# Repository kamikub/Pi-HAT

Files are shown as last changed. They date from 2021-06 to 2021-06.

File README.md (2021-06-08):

# PiHat_Group18

This is Group 18's Git repo, containing all relevant documentation, schematic, PCB and simulation files for the design of our PiHat.

The PiHat we designed is a frequency tuner: the user will be able to select a desired sound-frequency or pitch to listen for via a series of push buttons and through the operation of an onboard microphone, instrumentation op-amp and code written to the Pi, the PiHat will indicate whether the desired frequency is acquired or not (using LED's and a buzzer).

This repo includes all schematics, PCB, simulations and other relevant documentation that went into the design of this PiHat. For the most part, this was a modular design process – our PiHat was broken down into three submodules: power supply, LED/buzzer interface and operational amplifier. These submodules were individually designed and simulated on LTSpice and KiCad. The integration of all three submodules was developed on KiCad by means of a final PCB design of the PiHat as a whole.

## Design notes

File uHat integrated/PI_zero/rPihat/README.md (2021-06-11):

# Raspberry Pi Zero ~~pHat~~ uHat template

This a KiCad 5.0.0 template for a [Raspberry Pi Zero](https://www.raspberrypi.org/products/raspberry-pi-zero/) or [Raspberry Pi Zero W](https://www.raspberrypi.org/products/raspberry-pi-zero-w/) sized uHat. It is based on the [Raspberry Pi B+ Hat template](https://github.com/xesscorp/RPi_Hat_Template) from Xess Corp. They did all the hard work here.

Raspberry Pi Foundation has finally named these Raspberry Pi Zero sized hats which some called pHats. The new name is **Micro-Hat** or **uHat**. They also released a mechanical specification for them [here](https://github.com/raspberrypi/hats/blob/master/uhat-board-mechanical.pdf). Luckily these specifications exactly match the template. Note the new POE keepout area is not in this template. You will have to keep track of it yourself.

Both a thru-hole and a surface mount connector are provided, along with a different PCB edge for each. Just keep the PCB edge and connector type that you're using for your design and delete the others. The surface mount header is on the bottom of the board. Keep in mind if you flip it to the top side even/odd pins will be swapped unless you also switch the foot print to "Samtec_HLE-120-02-xxx-DV-BE-A_2x20_RPi_Top".

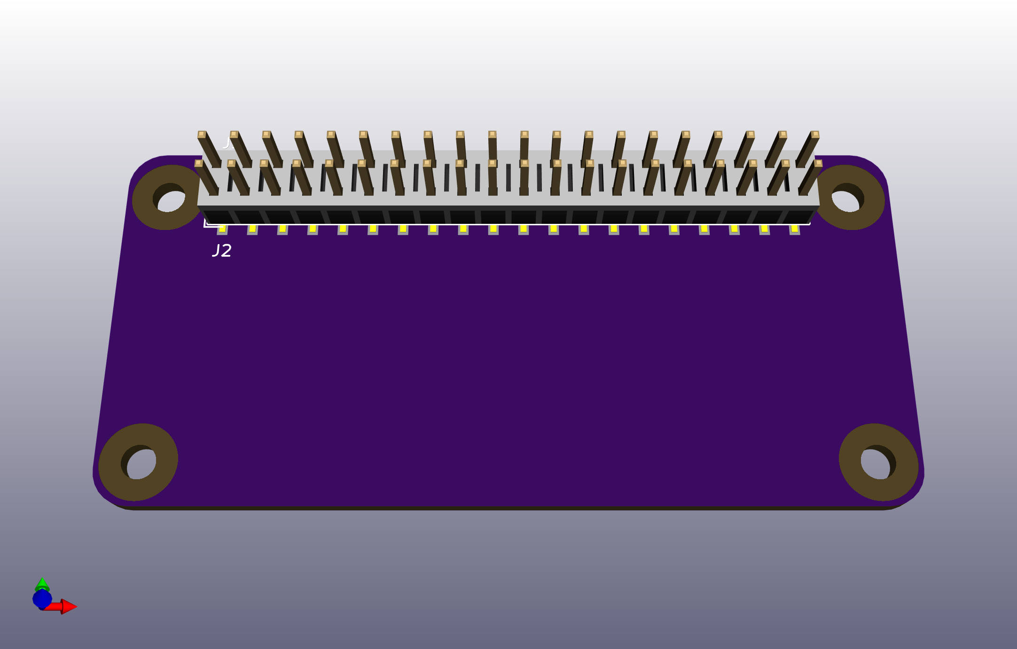
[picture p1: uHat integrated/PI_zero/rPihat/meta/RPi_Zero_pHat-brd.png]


## Using the Template

Follow the instructions listed in the original [Raspberry Pi B+ Hat template](https://github.com/xesscorp/RPi_Hat_Template) from XESS Corp.

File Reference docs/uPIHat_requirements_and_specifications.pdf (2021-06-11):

## uPIHat Requirements and Specifications

## Mechanical Specifications

Requirement | Specification(s) | Acceptance Test Criteria
With the addition of the MicroHat, the final weight of the Pi and MicroHat should not exceed 10kg | Weight of the microHAT should be taken into account when considering that the total weight should not exceed 10kg | Use a Scale to weigh the Pi including the Hat
MicroHat board needs to conform to the basic add-on board requirements | Make sure that after the integration of the subsystems, the board still conforms to the basic add-on board requirements | Check the basic add-on board requirements and compare it to your board

## Electrical Specifications

Requirement | Specification(s) | Acceptance Test Criteria
R1.2, R2.2: The input signal from the mic should not exceed 1V. | S1.2, S2.2: use a mic that’s output voltage is below 1V. | Test output signal from power regulator using LTspice
Microphone, op-amp requires 2V power supply. | Buck switching regulator should output 2V given a 3V input | Simulate input/output voltages on LTSpice.
Since we are using the 5V GPIO header we need to make sure it is safe to do so | Add a safety diode according to the design guide of the PI | Check the datasheet for the op-amp and power regulator to ensure that 5V will not damage the respective subsystem

## Functional Specifications

Requirement | Specification(s) | Acceptance Test Criteria
R1.1, R2.1, R3.1:The status LED’s and/or buzzer should show if desired frequency is met. | S3.1 Use 3 different coloured LED’s and a buzzer | Select known frequency signals stored in the Pi from the op-amp and check to see whether LED lights up and buzzer goes off
R3.2: Users could choose six notes that they would like to practice. | S3.2 a text file that can be edited on the Pi which will contain six frequencies that the user wants. | Press the buttons to change the different frequencies and note the change in the LED that lights up
R1.3, R2.3, R3.3: Users can choose which of the six predefined notes they would like to practice. | S1.1, S2.3, S3.3 Use 6 push buttons configured in a matrix | Simulate a text file to be processed in the Pi and switch between them using the buttons

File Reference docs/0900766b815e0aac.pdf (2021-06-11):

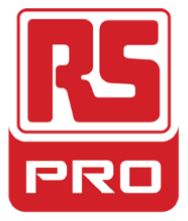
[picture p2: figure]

Datasheet

### RS Pro Continuous Internal Piezo Buzzer

ENGLISH

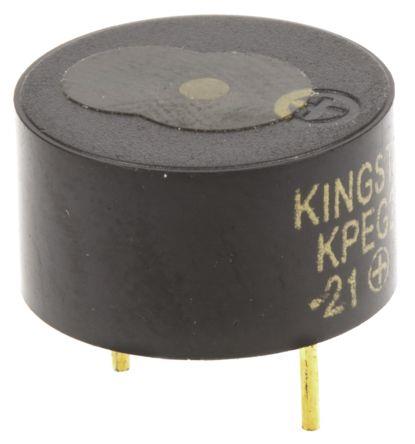
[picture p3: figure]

Specifications

RS Pro: 535-8253

Rated Frequency (Hz) | 4100 + 500
Operating Voltage Range (Vdc) | 3 ~ 16
Current Consumption (mA) | Max. 7@12Vdc
Sound Pressure Level (dB) | Min. 70@30cm@12Vdc
Tone | Continuous
Operating Temperature (°C) | -20 ~ +70
Storage Temperature (°C)
| -30 ~ +80
Weight (gram) | | 1.0
Material | Noryl (Black)

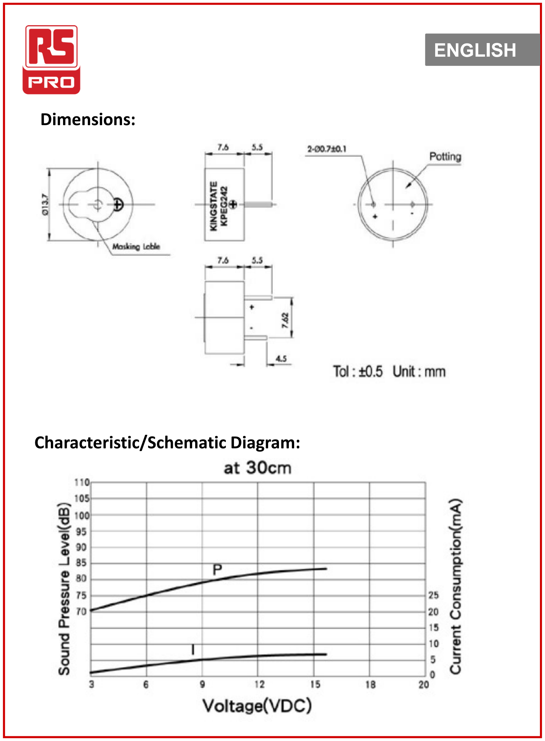
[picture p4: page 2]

ENGLISH

Dimensions:

Characteristic/Schematic Diagram:

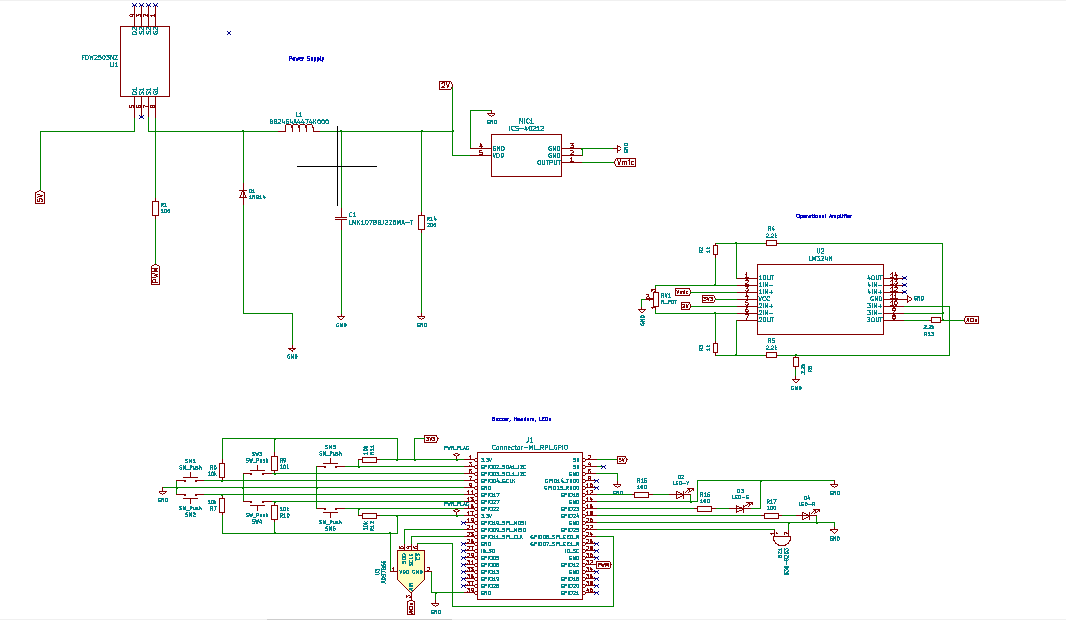
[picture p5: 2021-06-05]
Schematics/KiCad/Screenshots/IntegratedCircuit.PNG

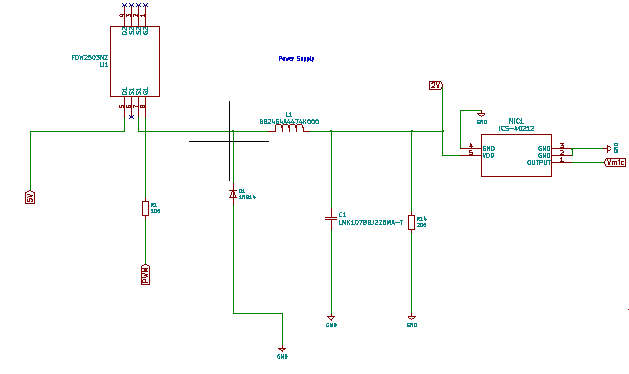
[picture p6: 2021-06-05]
Schematics/KiCad/Screenshots/PowerSupply.PNG

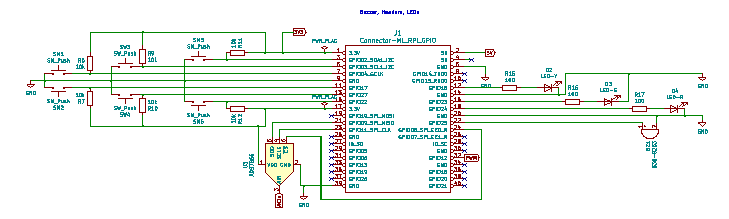
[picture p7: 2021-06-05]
Schematics/KiCad/Screenshots/HeadersBuzzerLEDs.PNG

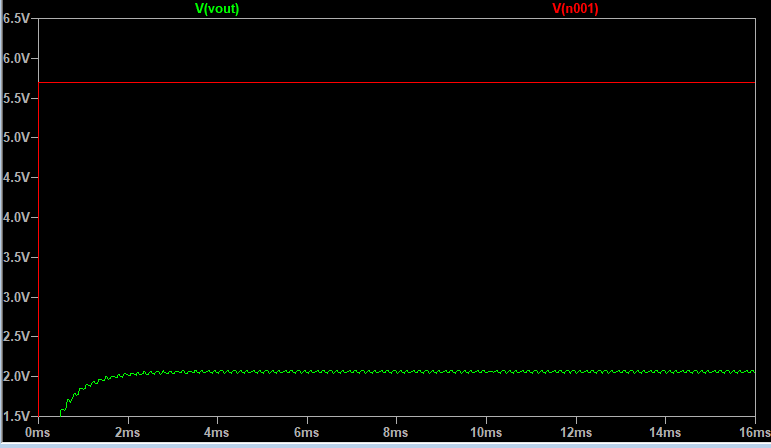
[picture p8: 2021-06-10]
Simulations/Power Supply Sim/PowerRegSim5V7.PNG

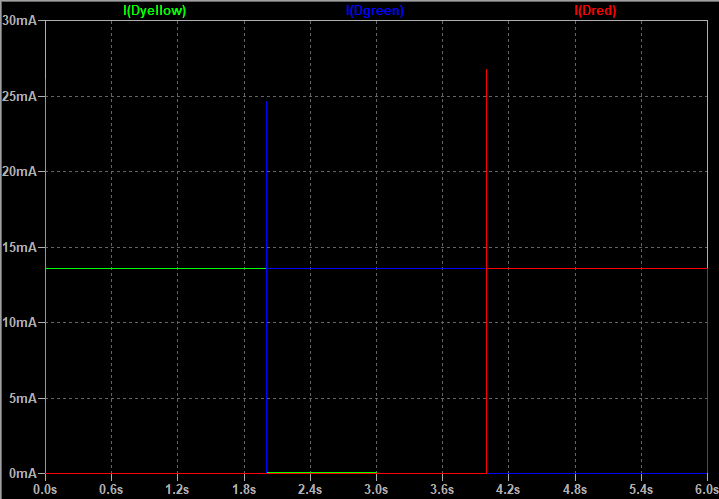
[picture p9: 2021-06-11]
Simulations/LED/Buttons Sim/ledsimu.png

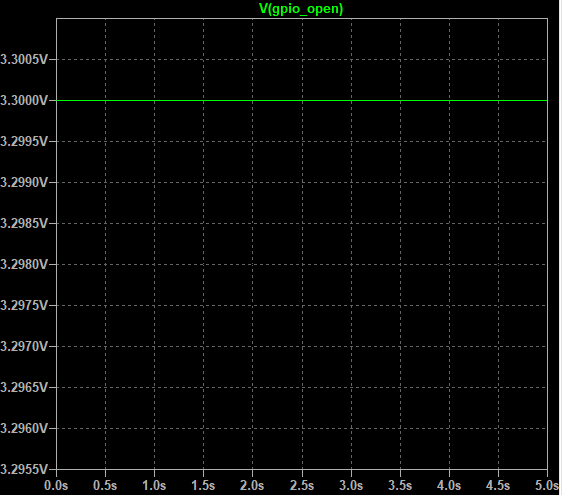
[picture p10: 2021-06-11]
Simulations/LED/Buttons Sim/open_GPIO_sim.png

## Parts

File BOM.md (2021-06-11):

# Frequency Tuner Bill of Materials 

## Power Supply:
- 1x 100 ohm resistor:             R0.50  
- 1x 200 ohm resistor:             R0.50 
- 1x MOSFET (FDW2501NZ):           R10.00
- 1x Capacitor (LMK107BBJ226MA_T): R8.00
- 1x Inductor (B82464A4474K000):   R24.00
- 1x Microphone (ICS-40212):       R30.00
- 1x Diode (1N914):                R9.50

## LEDs/Buzzer:
- 1x ADC (ADS7866):                R34.46
- 6x Switches (1825910-6)          R9.63
- 3x LEDS(150040VS73240/
     150040YS73240/150040RS73240)  R11.43
- 6x 10k ohm resistor:             R3.00
- 3x 100 ohm resistor:             R1.50
- 1x Piezo Buzzer (535-8253)       R16.89

## Op amp:
- 2x 1000 ohm resistor:            R1.00
- 4x 2200 ohm resistor:            R2.00
- 1x potentiometer:                R27.77
- 1x LM324N quad amplifier:        R67.11

## Subtotal: R257.29

Datasheets for all of the above components can be found in 'Referenced Docs'

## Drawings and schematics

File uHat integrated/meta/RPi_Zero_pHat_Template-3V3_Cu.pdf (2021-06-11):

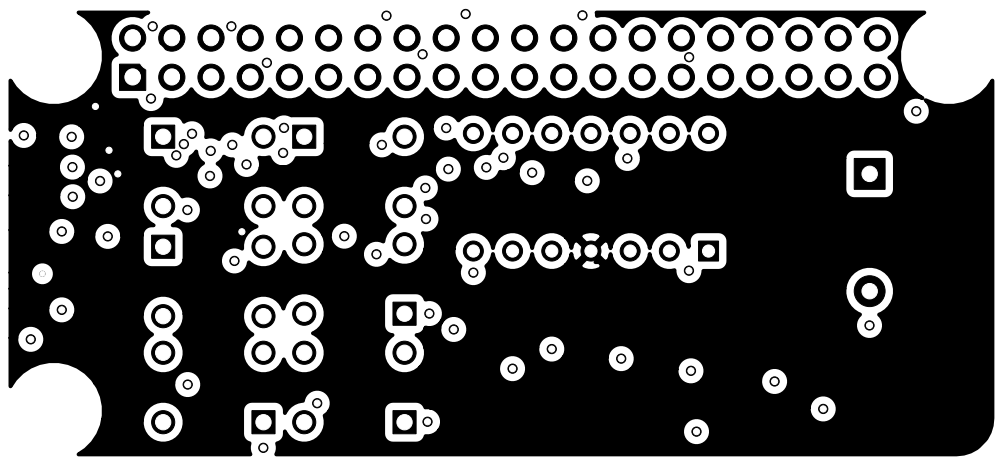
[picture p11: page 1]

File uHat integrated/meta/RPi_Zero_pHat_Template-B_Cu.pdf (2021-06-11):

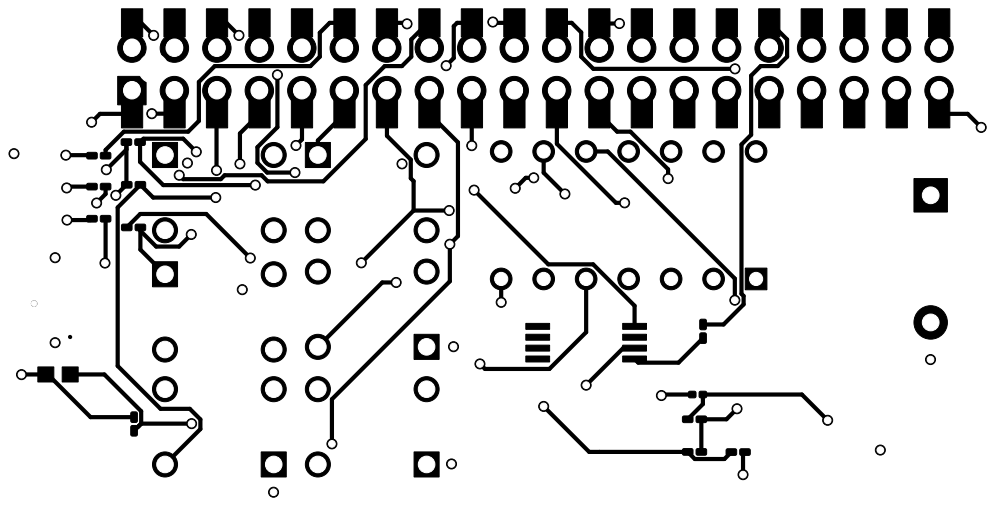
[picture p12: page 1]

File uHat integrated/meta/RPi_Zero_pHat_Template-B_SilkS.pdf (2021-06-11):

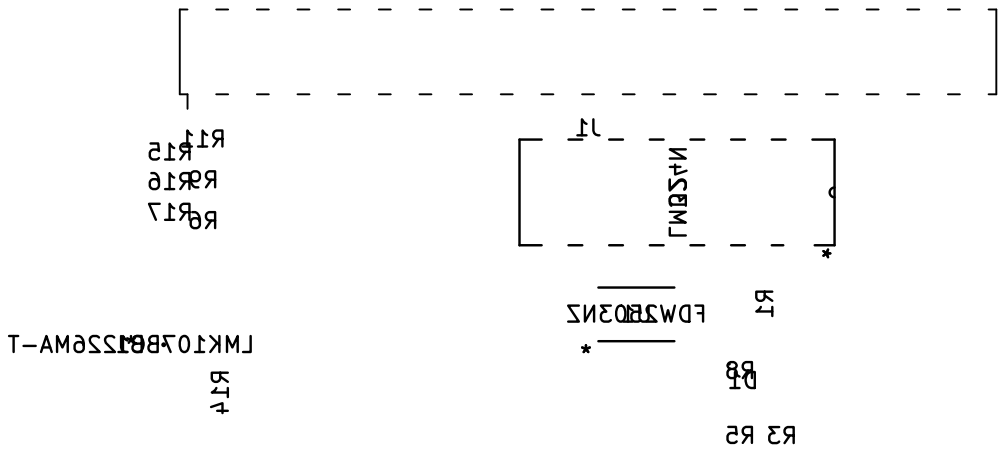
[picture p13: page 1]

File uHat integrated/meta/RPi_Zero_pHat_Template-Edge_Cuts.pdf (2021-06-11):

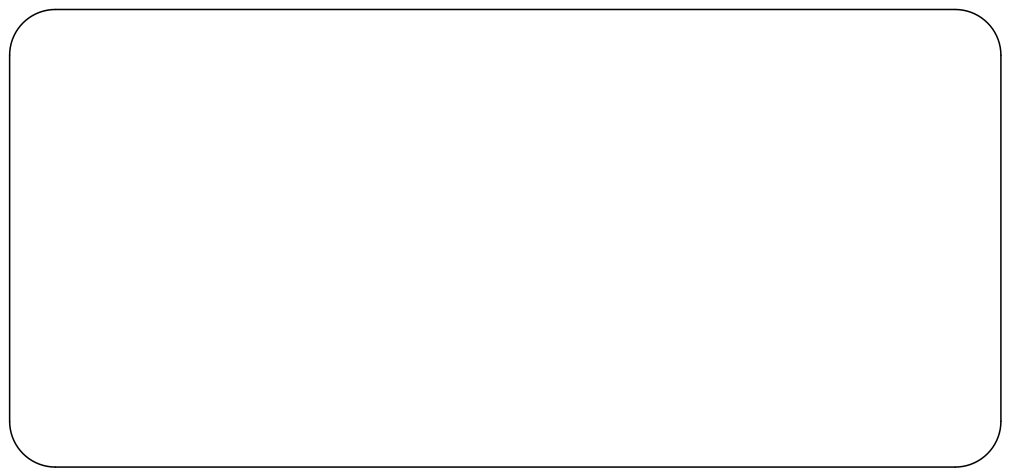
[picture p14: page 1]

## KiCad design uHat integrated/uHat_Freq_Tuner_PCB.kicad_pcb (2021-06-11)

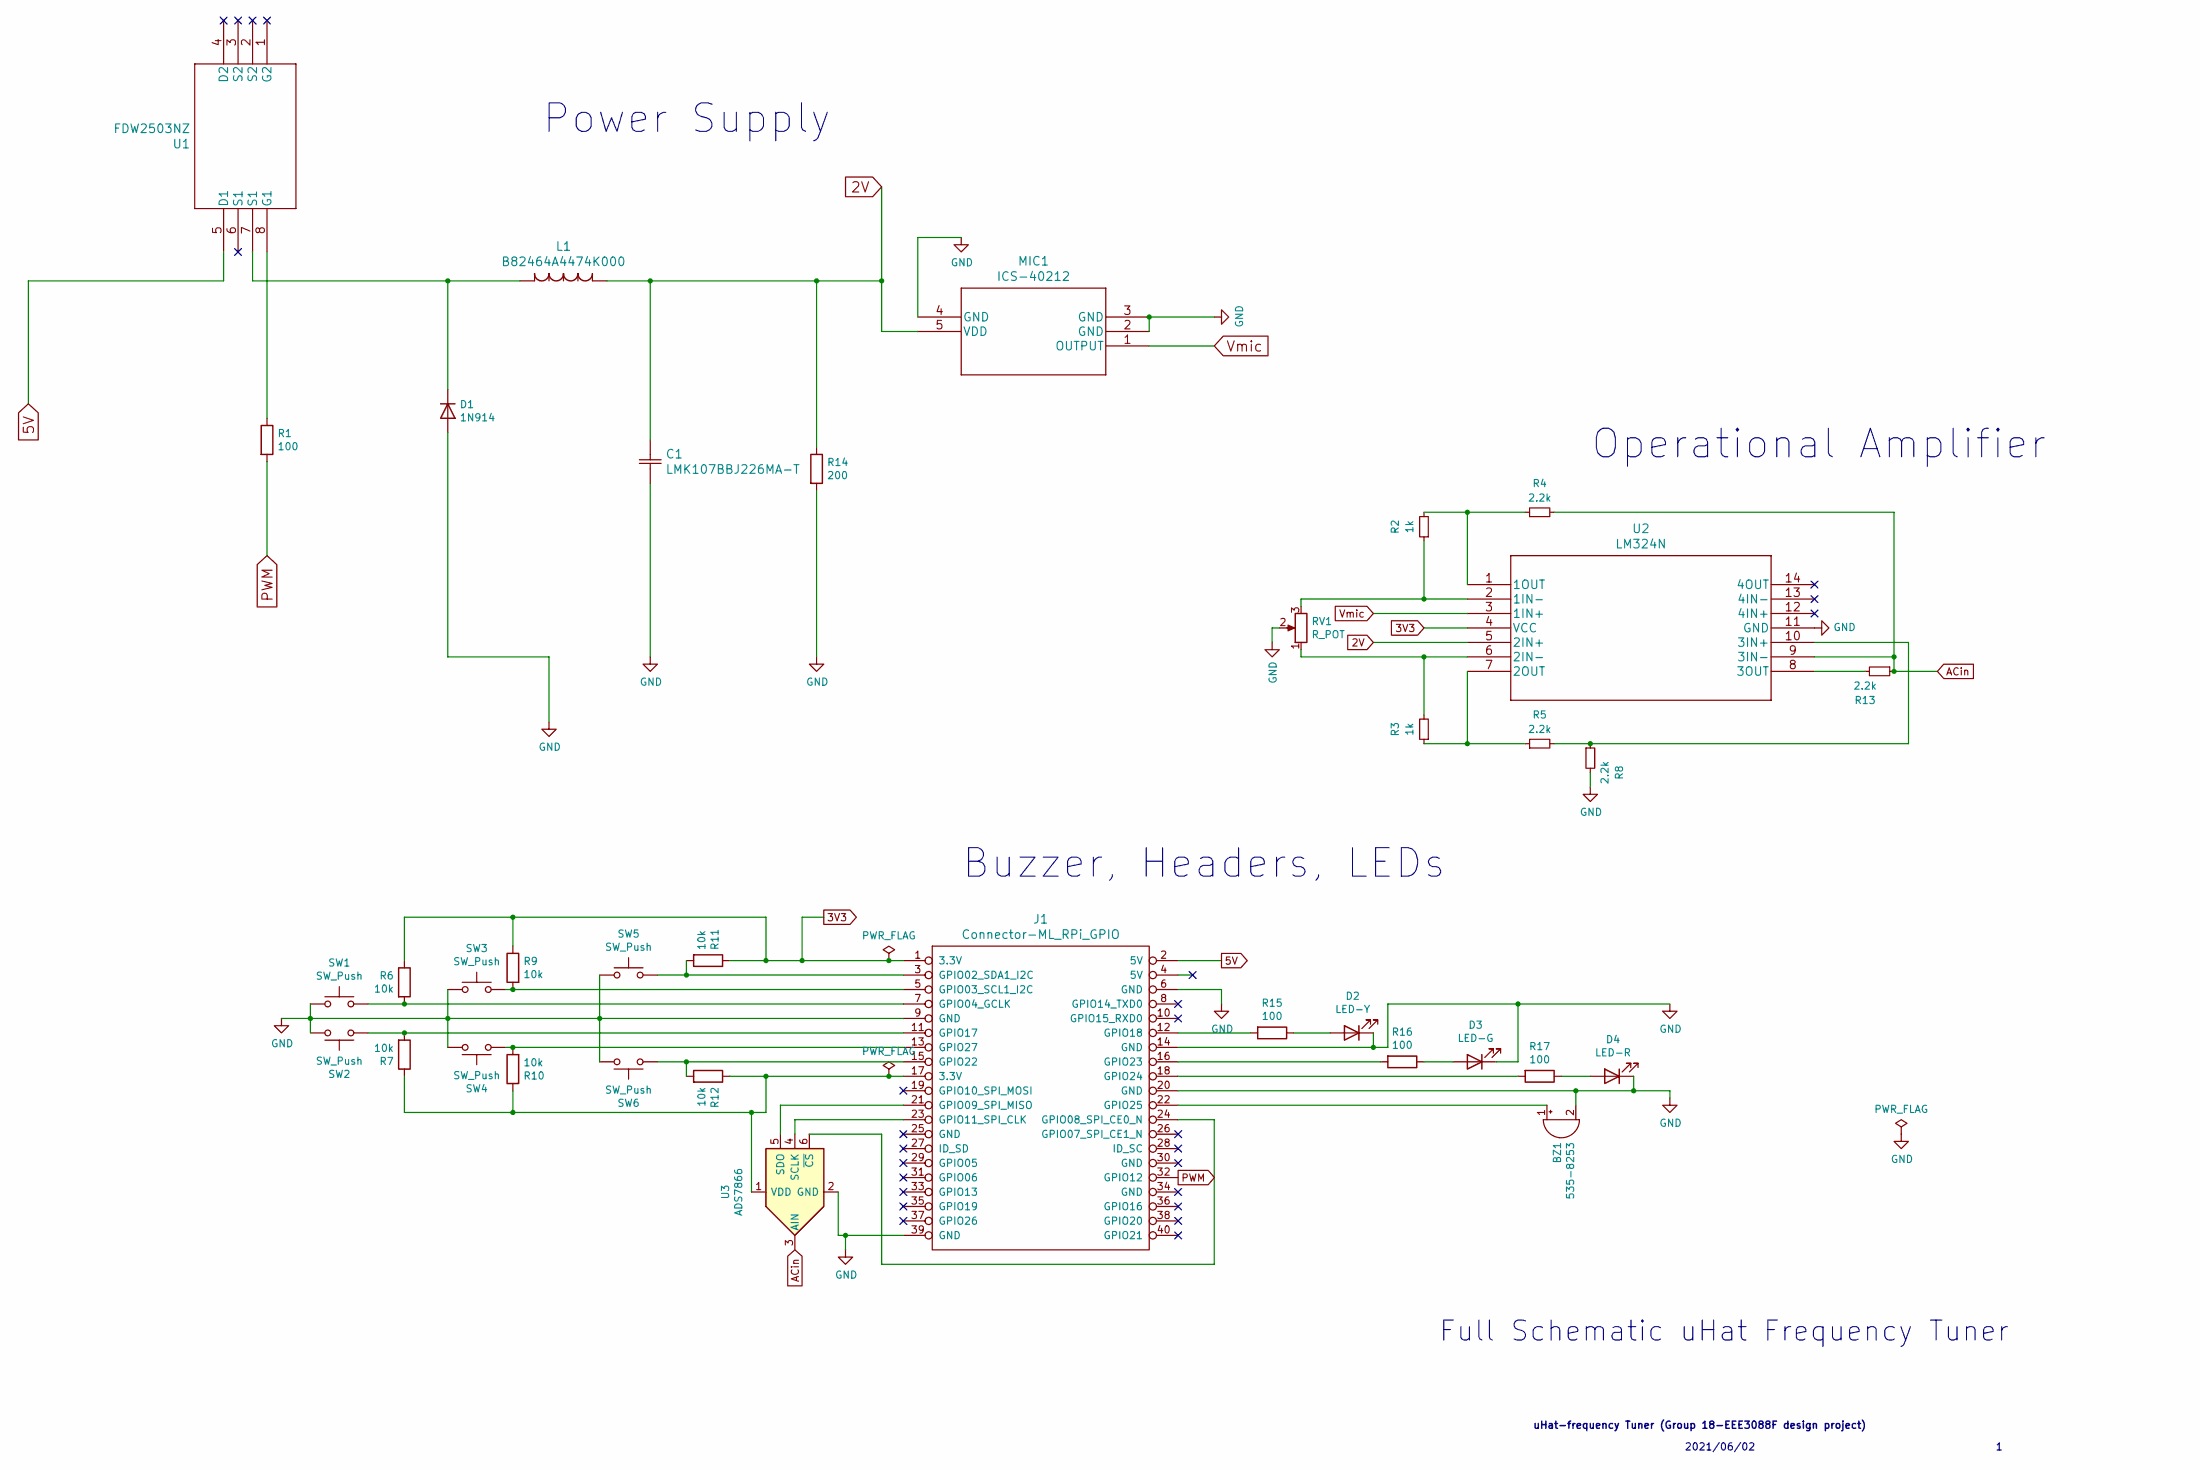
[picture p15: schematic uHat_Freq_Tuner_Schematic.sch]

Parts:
BZ1: 535-8253; Buzzer_15x7.5RM7.6
C1: LMK107BBJ226MA-T
D1: 1N914; D_0201_0603Metric
D2: LED-Y; LED_0402_1005Metric_Pad0.77x0.64mm_HandSolder
D3: LED-G; LED_0402_1005Metric_Pad0.77x0.64mm_HandSolder
D4: LED-R; LED_0402_1005Metric_Pad0.77x0.64mm_HandSolder
J1: Connector-ML_RPi_GPIO; Samtec_HLE-120-02-xxx-DV-BE-A_2x20_P2.54mm_Horizontal
L1: B82464A4474K000
MIC1: ICS-40212
R1, R15, R16, R17: 100; R_0201_0603Metric_Pad0.64x0.40mm_HandSolder
R2, R3: 1k; R_0201_0603Metric_Pad0.64x0.40mm_HandSolder
R4, R5, R8, R13: 2.2k; R_0201_0603Metric_Pad0.64x0.40mm_HandSolder
R6, R7, R9, R10, R11, R12: 10k; R_0201_0603Metric_Pad0.64x0.40mm_HandSolder
R14: 200; R_0201_0603Metric_Pad0.64x0.40mm_HandSolder
RV1: R_POT; Potentiometer_ACP_CA6-VSMD_Vertical
SW1, SW2, SW3, SW4, SW5, SW6: SW_Push; 1825910-6
U1: FDW2503NZ
U2: LM324N
U3: ADS7866; ADS7866IDBVT

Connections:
2V: C1.1, L1.1, MIC1.5 (VDD), R14.1, U2.5 (2IN+)
3V3: J1.1 (3.3V), R6.1, R9.1, R11.1, U2.4 (VCC)
5V: J1.2 (5V), U1.5 (D1)
ACin: R4.2, R13.1, U2.9 (3IN-), U3.3 (AIN)
GND: BZ1.2 (+), C1.2, D1.2 (A), D2.1 (K), D3.1 (K), D4.1 (K), J1.6 (GND), J1.9 (GND), J1.14 (GND), J1.20 (GND), J1.39 (GND), MIC1.2 (GND), MIC1.3 (GND), MIC1.4 (GND), R8.2, R14.2, RV1.2, SW1.2, SW2.2, SW3.1, SW4.1, SW5.1, SW6.1, U2.11 (GND), U3.2 (GND)
unnamed: BZ1.1 (-), J1.22 (GPIO25)
unnamed: D1.1 (K), L1.2, U1.7 (S1)
unnamed: D2.2 (A), R15.1
unnamed: D3.2 (A), R16.1
unnamed: D4.2 (A), R17.1
unnamed: J1.3 (GPIO02_SDA1_I2C), R11.2, SW5.2
unnamed: J1.5 (GPIO03_SCL1_I2C), R9.2, SW3.2
unnamed: J1.7 (GPIO04_GCLK), R6.2, SW1.1
unnamed: J1.11 (GPIO17), R7.2, SW2.1
unnamed: J1.12 (GPIO18), R15.2
unnamed: J1.13 (GPIO27), R10.2, SW4.2
unnamed: J1.15 (GPIO22), R12.2, SW6.2
unnamed: J1.16 (GPIO23), R16.2
unnamed: J1.17 (3.3V), R7.1, R10.1, R12.1, U3.1 (VDD)
unnamed: J1.18 (GPIO24), R17.2
unnamed: J1.21 (GPIO09_SPI_MISO), U3.5 (SDO)
unnamed: J1.23 (GPIO11_SPI_CLK), U3.4 (SCLK)
unnamed: J1.24 (GPIO08_SPI_CE0_N), U3.6 (~CS)
unnamed: R1.1, U1.8 (G1)
unnamed: R2.1, RV1.3, U2.2 (1IN-)
unnamed: R2.2, R4.1, U2.1 (1OUT)
unnamed: R3.1, R5.1, U2.7 (2OUT)
unnamed: R3.2, RV1.1, U2.6 (2IN-)
unnamed: R5.2, R8.1, U2.10 (3IN+)
unnamed: R13.2, U2.8 (3OUT)
PWM: J1.32 (GPIO12), R1.2
Vmic: MIC1.1 (OUTPUT), U2.3 (1IN+)

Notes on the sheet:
2021/06/02
Full Schematic uHat Frequency Tuner
uHat-frequency Tuner (Group 18-EEE3088F design project)
Operational Amplifier
Buzzer, Headers, LEDs
Power Supply

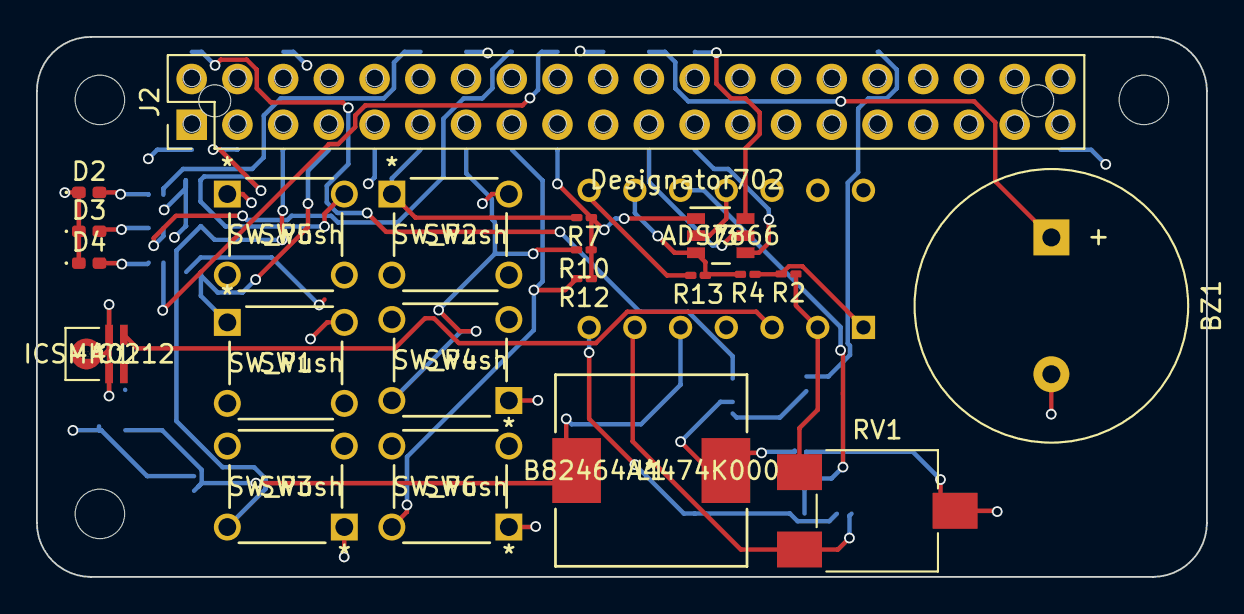
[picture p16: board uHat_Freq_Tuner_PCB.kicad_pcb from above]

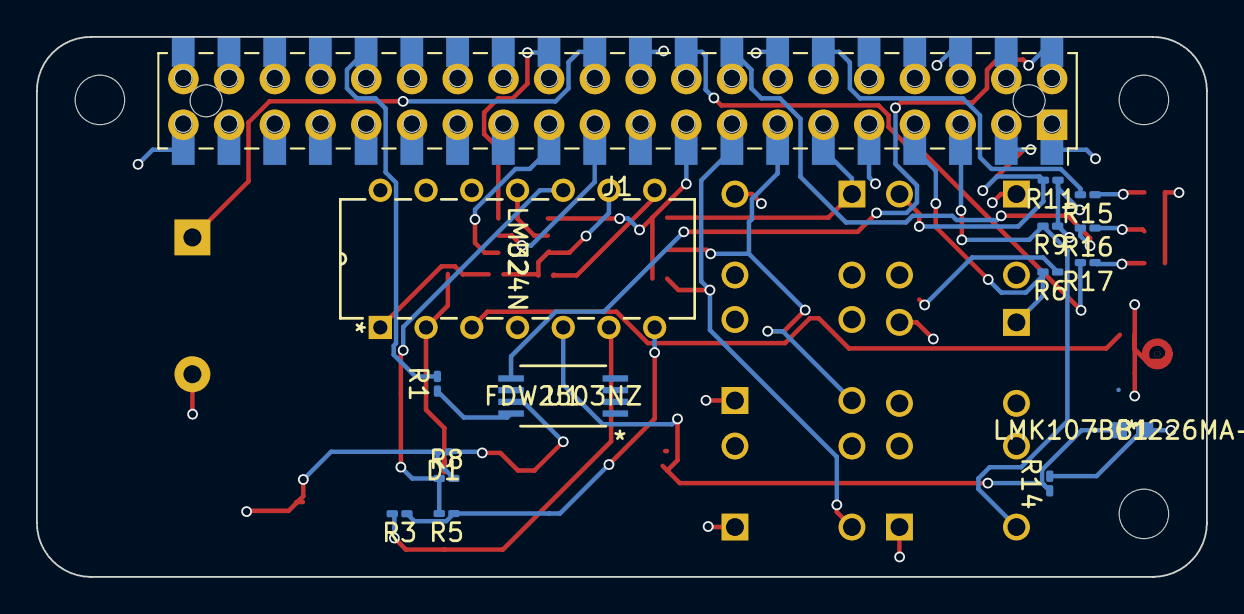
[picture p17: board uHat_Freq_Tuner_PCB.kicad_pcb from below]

Board: 4 copper layers, 65.0 x 30.0 mm, 37 parts (16 on the bottom side), 32 nets.

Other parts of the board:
J2: RPi_GPIO; PinHeader_2x20_P2.54mm_Vertical

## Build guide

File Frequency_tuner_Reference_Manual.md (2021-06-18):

Frequency Tuner
---------------------------------------------------------------------
The products intended use is as a frequency tuner allowing a user to 
tune their desired instrument in an efficient manner. It can also
be used as a vocal trainer when fine tuning pitch.

---------------------------------------------------------------------

Features and accesories
-The instrumentation amplifier will be a small uPiHat, conforming to
 the HAT basic requirements which are described next.
-A board can only be called a HAT if:
 1. It conforms to the basic add-on board requirements
 2. It has a valid ID EEPROM (including vendor info, GPIO map and 
    valid device tree information).
 3. It has a full size 40W GPIO connector.
 4. It follows the HAT mechanical specification
 5. It uses a GPIO connector that spaces the HAT at least 8mm from the
    Pi (i.e. uses spacers 8mm or larger)
 6. If back powering via the GPIO connector the HAT must be able to
    supply a minimum of 1.3A continuously to the Pi.

----------------------------------------------------------------------    

Description of main submodules

- Power regulator submodule responsible for powering the microphone and
  acting as one of the inputs to the amplifier submodule.
- LED, Buzzer, and Headers submodule acting as interfaces for the
  intended use. (LED's light up as confirmation, buzzer sounding off as
  confirmation, headers to coonnnect to PI)
- Amplifier responsible for amplifying microphone signal (to get a better
  reading of the information) before being passed to the ADC.

---------------------------------------------------------------------- 

Safety Warnings
- Since we are using the 5V GPIO header we need to make sure it is safe
  to do so.
- The input signal from the mic should not exceed 1V.
- Output of power regulator should not vary too much from 2V to protect
  microphone.
- Add a safety diode according to the design guide of the PI

----------------------------------------------------------------------

Technical Specifications
- Use 3 different coloured LED’s and a buzzer.
- A text file that can be edited on the Pi which will contain six
  frequencies that the user wants.
- Use 6 push buttons configured in a matrix.
- Buck switching regulator should output 2V given a 3V input.
- Weight of the microHAT should be taken into account when considering
  that the total weight should not exceed 10kg
- Make sure that after the integration of the subsystems, the board
  still conforms to the basic add-on board requirements

-----------------------------------------------------------------------

Contact Details
- ZLLJUL001@myuct.ac.za
- KMLSAL001@myuct.ac.za
- BTJLUK001@myuct.ac.za

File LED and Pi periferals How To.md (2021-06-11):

## LEDS:

The LEDs operate fairly simple. Assuming the user has selected a frequency from the buttons (see below) after singing/playing/generating the wave that they would like to test, an LED would light up. Each LED represents as follows:
Yellow- pitch is too Low.
Green- pitch is on key (optional: buzzer would sound)
Red- Pitch is too high

## Switches:

The switches are pressed to select which frequency the user would like to tune to. They are arranged in the following arrangement:

GPIO PIN HEADER (PCB TOP)

1&nbsp;&nbsp;&nbsp;&nbsp;&nbsp;&nbsp;4

2&nbsp;&nbsp;&nbsp;&nbsp;&nbsp;&nbsp;5

3&nbsp;&nbsp;&nbsp;&nbsp;&nbsp;&nbsp;6

Each by default corresponds (by default) to the following frequencies:
1: 82.41 Hz  (E_2)

2: 110.00 Hz (A_2)

3: 146.83 Hz (D_3)

4: 196.00 Hz (G_3)

5: 246.94 Hz (B_3)

6: 329.63 Hz (E_4)

User may alter this by altering "software/freq.txt"

## Buzzer:
On default the buzzer is set to go off when the desired frequency is reached, the user is able to turn this functionality off but altering the code provided (as per the instructions)

## Others:
The rest of the devices in the subsystem are designed as the subsystem requires. These require no input/alterations from the user as it may distrupted the performance of the uHat.

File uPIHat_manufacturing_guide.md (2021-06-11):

## PCB manufacturing guide for the frequency tuner

A link to the Bill of Materials can be found here: https://gitlab.com/beanzille/pihat_group18/-/blob/main/BOM.md

After the PCB was completely designed using KiCad the drill files and Gerber files were
plotted and output from KiCad.

1. The drill and gerber files can be found in the following link: https://gitlab.com/beanzille/pihat_group18/-/tree/main/uHat%20integrated/meta
2. These files need to be downloaded and shared to the manufacturer.
3. The manufacturer then exports the Gerber and drill files into software they can interpret
   and the PCB is manufactured.

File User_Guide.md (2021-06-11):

## How to use the uHAT Frequency Tuner

### Required:

- Raspberry Pi (with 40 pin GPIO)
- uHAT Frequency Tuner
- Instrument/desired frequency to tune to.

1. Connect the uPIHat to the Pi Zero by inserting the male pins into the female
   pins of the uPIHat
2. The Pi Zero needs to be powered first by using a desktop or pc using the micro USB port.
3. The PI Zero then powers the uPIHat.
4. Do not turn the potentiometer on the amplifier submodule, it should remain in its preset
   position unless the user is using the amplifier for its second use case (vocal trainer).
5. If the user is using the amplifier in its second use case then refer to the
   Amplifier_How_To_Guide in the repository. 
3. Select a frequency using one of the push buttons .........

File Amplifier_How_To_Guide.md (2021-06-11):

Author: Luke Baatjes
Date: 10 June 2021

--------------------------------------------------------------------------------------------------------------

How to connect and use subsystem 3, the amplifier stage of the micro PIHat.

This How-to guide serves to simplify the users task in implementing the amplifier stage in the microPIHat.
The guide will be short as the amplifier is simple to use and the steps are easy to implement.
This guide applies to the user (mainly musicians who need help in tuning their instruments or correcting
pitch while doing vocal training).
It is important that the user at least understands what an amplifier does in order to fully understand the
context of the How-to.

All subsystems are directly interconnected and have no connections via connector pins therefore there is
no individual need to connect one subsystem to the next.
The integration of all 3 subsystems simplifies the use of the microPIHat and therefore requires no
extra help from the user in the PIHat's primary use case.

For the PIHat's secondary use case where the gain of the amplifer can be changed to produce a desired
output value, the following simple steps apply:

Step 1:
	If the user should notice that the tuner does not produce the optimum sound for the note after
	tuning then the user should turn the potentiometer (on the amplifier) anti-clockwise to decrease
	the gain resistor and therefore increase the gain of the amplifier.

Step 2:
	Repeat Step 1 if necessary or if necessary turn the potentiometer clockwise accordingly.

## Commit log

2021-06-04 Added Schematics folder
2021-06-04 Deleted Schematics
2021-06-04 Added schematics
2021-06-04 Added KiCad folder
2021-06-04 Added Power Supply to Simulations
2021-06-04 Added LED folder to simulations
2021-06-04 Upload Power Supply LTSpice schematic
2021-06-04 Added Power Supply
2021-06-04 Upload New File
    [Integrated_Schematic.sch]
2021-06-04 Submodule2 first try
    [Submodule2.sch]
2021-06-04 Submodule 3 attempt 2
    [Submodule3.sch]
2021-06-04 Upload of J1 PI header schematic
2021-06-04 Upload J1 PI header footprint
2021-06-04 Upload U1 quad op-amp footprint
2021-06-04 Upload U1 quad op-amp schematic
2021-06-05 Replace PowerSupply.PNG
2021-06-05 Upload Headers, Buzzer and LEDs
2021-06-05 Upload of the project assignement 3 PCB file
    [IA2.kicad_pcb]
2021-06-05 Replace Project assignement 3 PCB file with correct one
    [IA2.kicad_pcb]
2021-06-09 Replace PowerSupply.sch
    [PowerSupply.sch]
2021-06-10 Upload of amplifier circuit schematic
2021-06-10 Upload of amplifier input signals V1(mic signal) and V2(power regulator)
2021-06-10 Upload of output after an increase fluctuation in V2(power regulator)
2021-06-10 Upload of output after increase in potentiometer resistance
2021-06-11 Uploaded Integrated Circuit
    [IA2.kicad_pcb, RPi_Zero_pHat_Template.kicad_pcb, RPi_Zero_pHat_Template.sch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]
2021-06-11 updating folder
    [IA2.kicad_pcb, RPi_Zero_pHat_Template.kicad_pcb, RPi_Zero_pHat_Template.sch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]
2021-06-11 Deleted temp folder
    [uHat_Freq_Tuner_PCB.kicad_pcb, uHat_Freq_Tuner_Schematic.sch]
2021-06-11 Updated folder
    [IA2.kicad_pcb, RPi_Zero_pHat_Template.kicad_pcb, RPi_Zero_pHat_Template.sch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]
2021-06-11 Update LED and Pi peripherals How To. and proper naming
2021-06-11 Update LED and Pi periferals How To.md better formatting
2021-06-11 Update LED and Pi periferals How To.md
2021-06-11 Add a manufacturing guide for the PCB
2021-06-11 Subsystem3(leds etc) v1
2021-06-11 Replace ADCHeaderLEDsbuttons.asc v2 replaced ADC to the better one
2021-06-11 LEDs operational simulation
2021-06-11 Simulation of buttons closed
2021-06-11 open buttons
2021-06-11 LED operation .plt
2021-06-11 closed switch plt
2021-06-11 open switches plt
2021-06-11 ADC datasheet
2021-06-11 RED LED
2021-06-11 Update BOM.md complete
2021-06-11 LED GREEN
2021-06-11 LED Yellow
2021-06-18 Upload Integrated Schematic dependant File

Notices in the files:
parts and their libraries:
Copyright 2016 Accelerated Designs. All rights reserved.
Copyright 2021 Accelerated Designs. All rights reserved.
